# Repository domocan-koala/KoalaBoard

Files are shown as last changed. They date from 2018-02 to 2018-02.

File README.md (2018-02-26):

# KoalaBoard

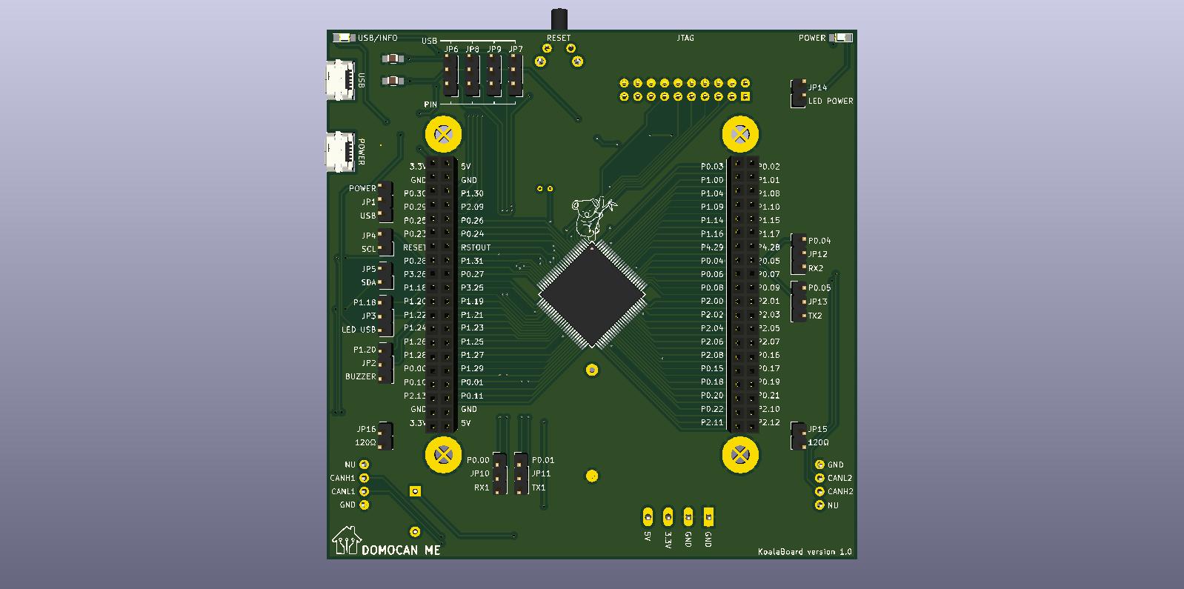
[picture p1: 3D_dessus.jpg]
Koalaboard Domocan


## Présentation

La KoalaBoard permet d'intégrer facilement la technologie ARM Cortex-M3 dans le système domotique [Domocan Master Édition](https://www.abcelectronique.com/bigonoff/forum/forumdisplay.php?fid=22). Ses deux connecteurs regroupent l’intégralité des entrées et sorties disponibles pour accueillir une [carte fille](https://github.com/domocan-koala/KoalaBoard_Carte-fille-template) complémentaire qui viendra spécialiser son utilisation dans votre installation. Les options disponibles se configurent grâce à des jumpers en fonction des besoins de l’utilisateur et de la carte fille qui va lui être associée.

## Caractéristiques techniques

* Alimentation 5V micro USB
* LPC1768 cadencé à 100MHz
* Connecteur JTAG 2x10 pins
* USB Slave
* Deux drivers CAN (*SN65HVD230*)
* Mémoire EEPROM (*24LC512*)
* Buzzer
* Support de pile 2032 et quartz pour le RTC
* Une led USB/INFO

## Configuration des jumpers

* **JP1** : Sélection de l'alimentation. (*Sans jumper, la carte doit être alimentée par la carte fille*)
* **JP2** : Active le Buzzer. (*La carte fille ne peut plus utiliser P1.20*)
* **JP3** : Active la LED USB/INFO. (*La carte fille ne peut plus utiliser P1.18*)
* **JP4** et **JP5** : Active la mémoire EEPROM. (*Ainsi que les deux résistances de pullup 4.7K*)
* **JP6**, **JP7**, **JP8** et **JP9** : Active l'USB Slave. (*La carte fille ne peut plus utiliser P0.29, P0.30, P1.30 et P2.09*)
* **JP10** et **JP11** : Active CAN1. (*La carte fille ne peut plus utiliser P0.00 et P0.01*)
* **JP12** et **JP13** : Active CAN2. (*La carte fille ne peut plus utiliser P0.04 et P0.05*)
* **JP14** : Active la LED POWER
* **JP15** : Active la résistance de terminaison CAN2
* **JP16** : Active la résistance de terminaison CAN1

## Historique
	
	* 23/02/18 V1.0 : Première version mise en ligne

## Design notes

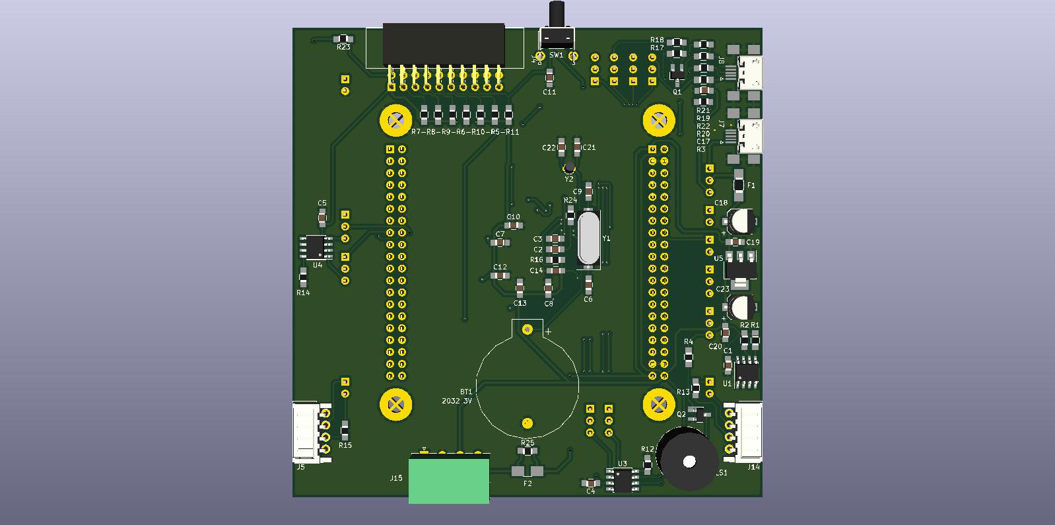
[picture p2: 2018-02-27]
3D_dessous.jpg

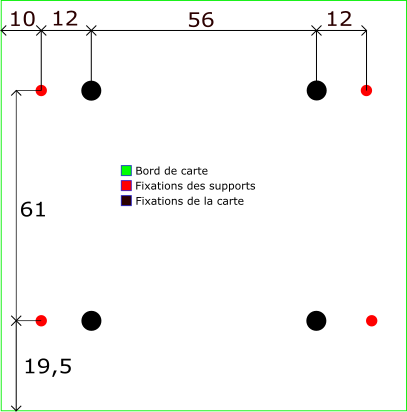
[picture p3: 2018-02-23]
Fixations.png

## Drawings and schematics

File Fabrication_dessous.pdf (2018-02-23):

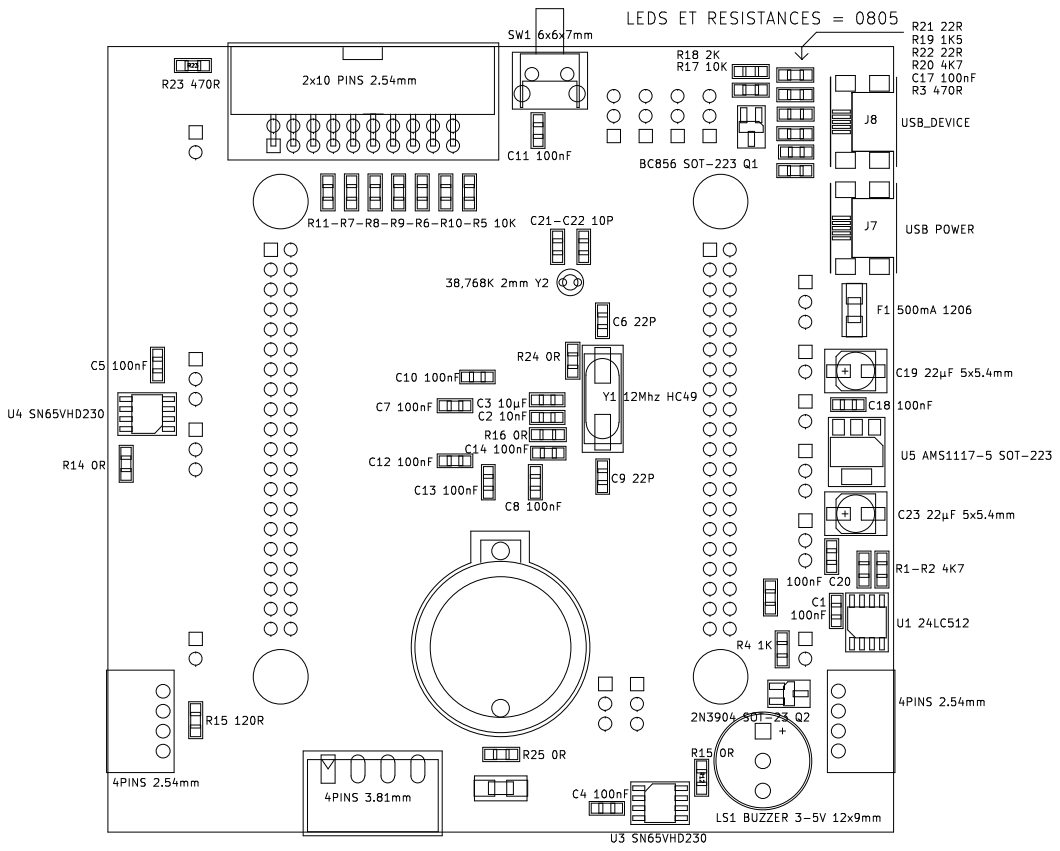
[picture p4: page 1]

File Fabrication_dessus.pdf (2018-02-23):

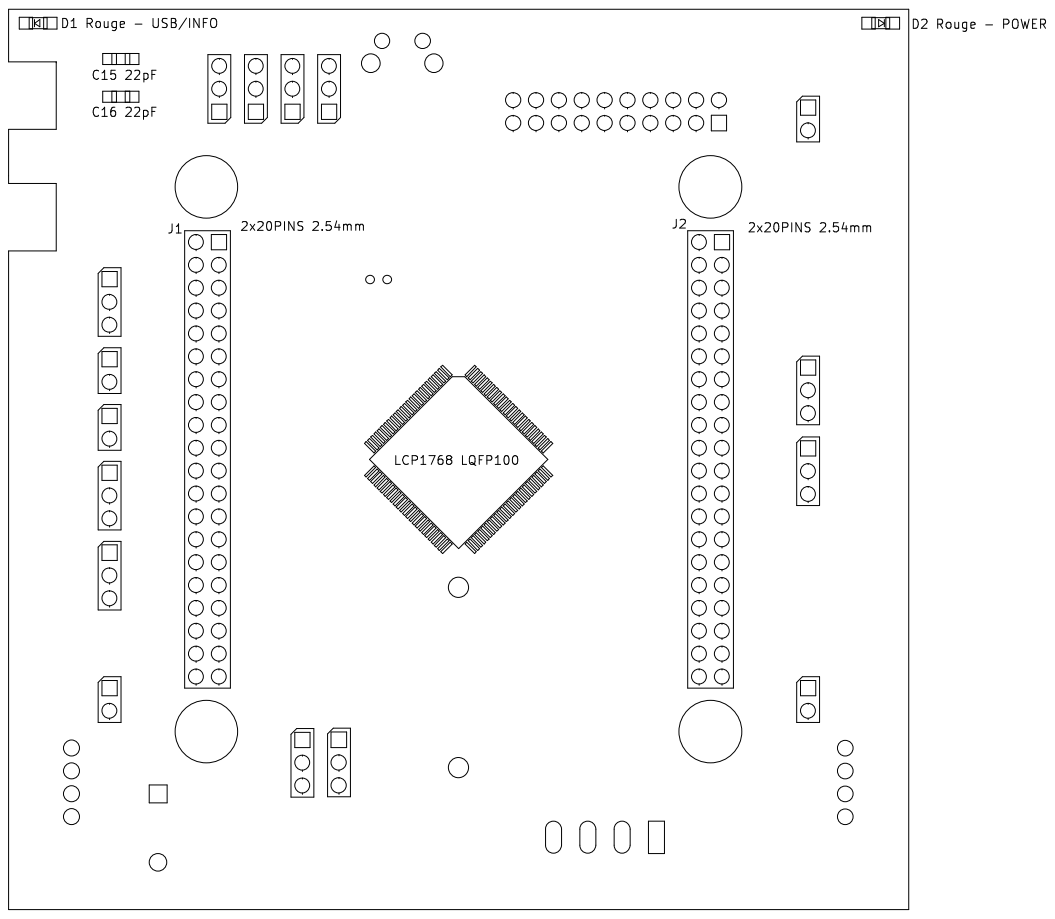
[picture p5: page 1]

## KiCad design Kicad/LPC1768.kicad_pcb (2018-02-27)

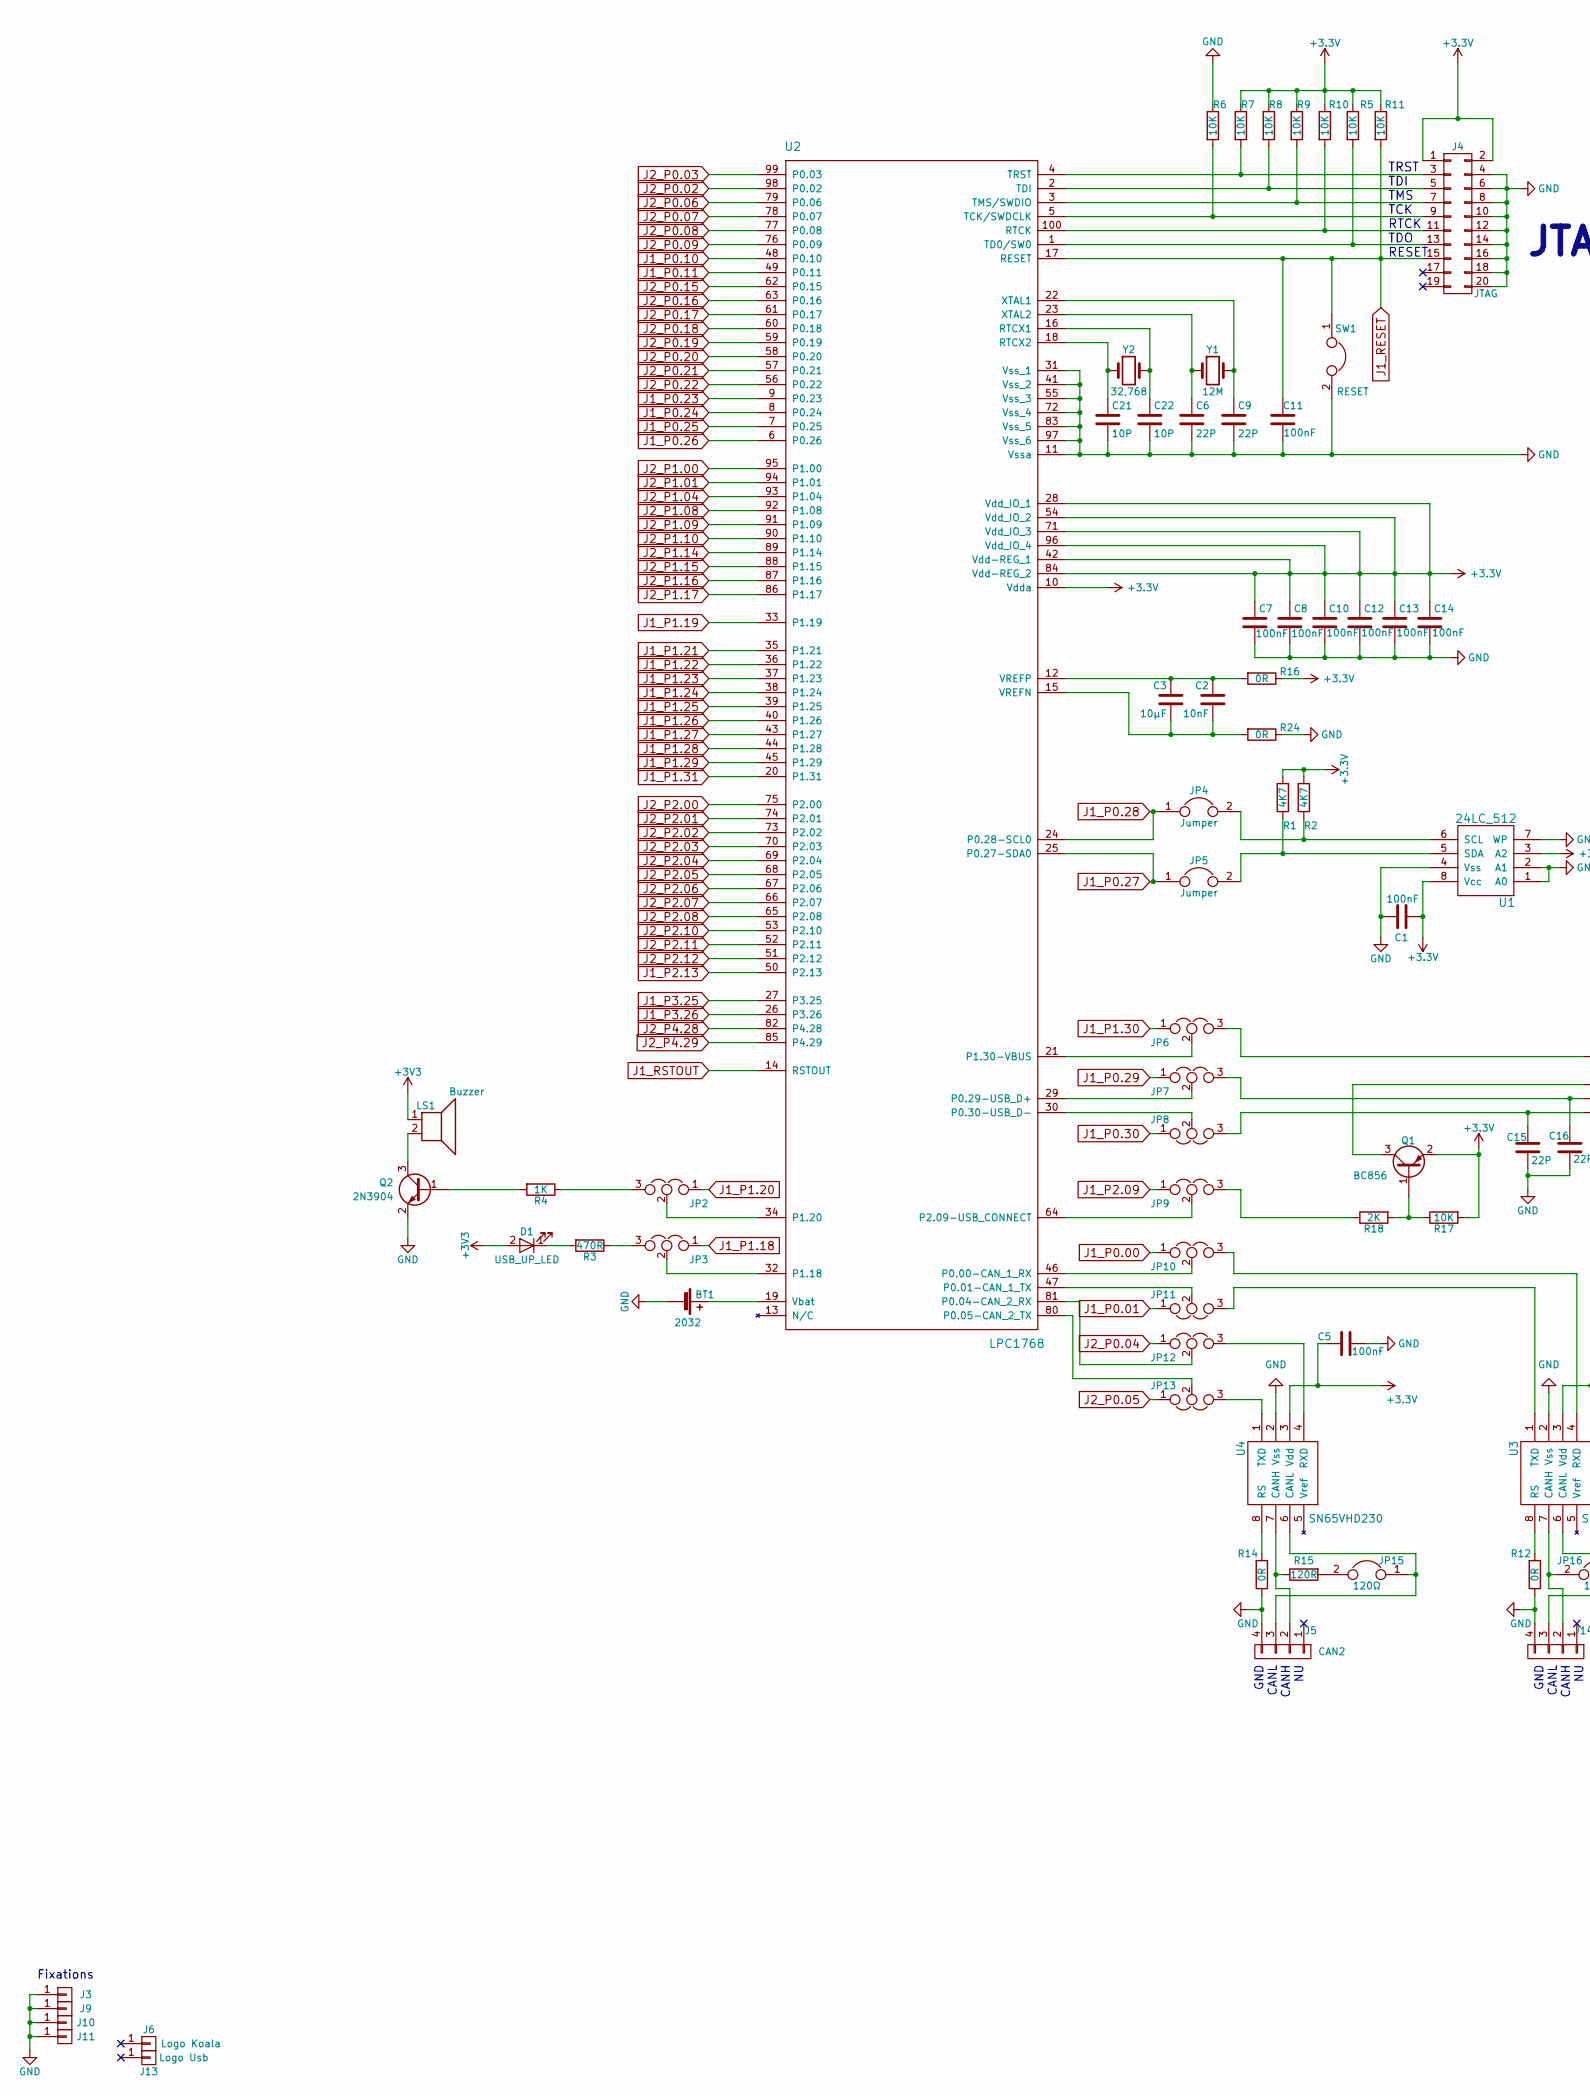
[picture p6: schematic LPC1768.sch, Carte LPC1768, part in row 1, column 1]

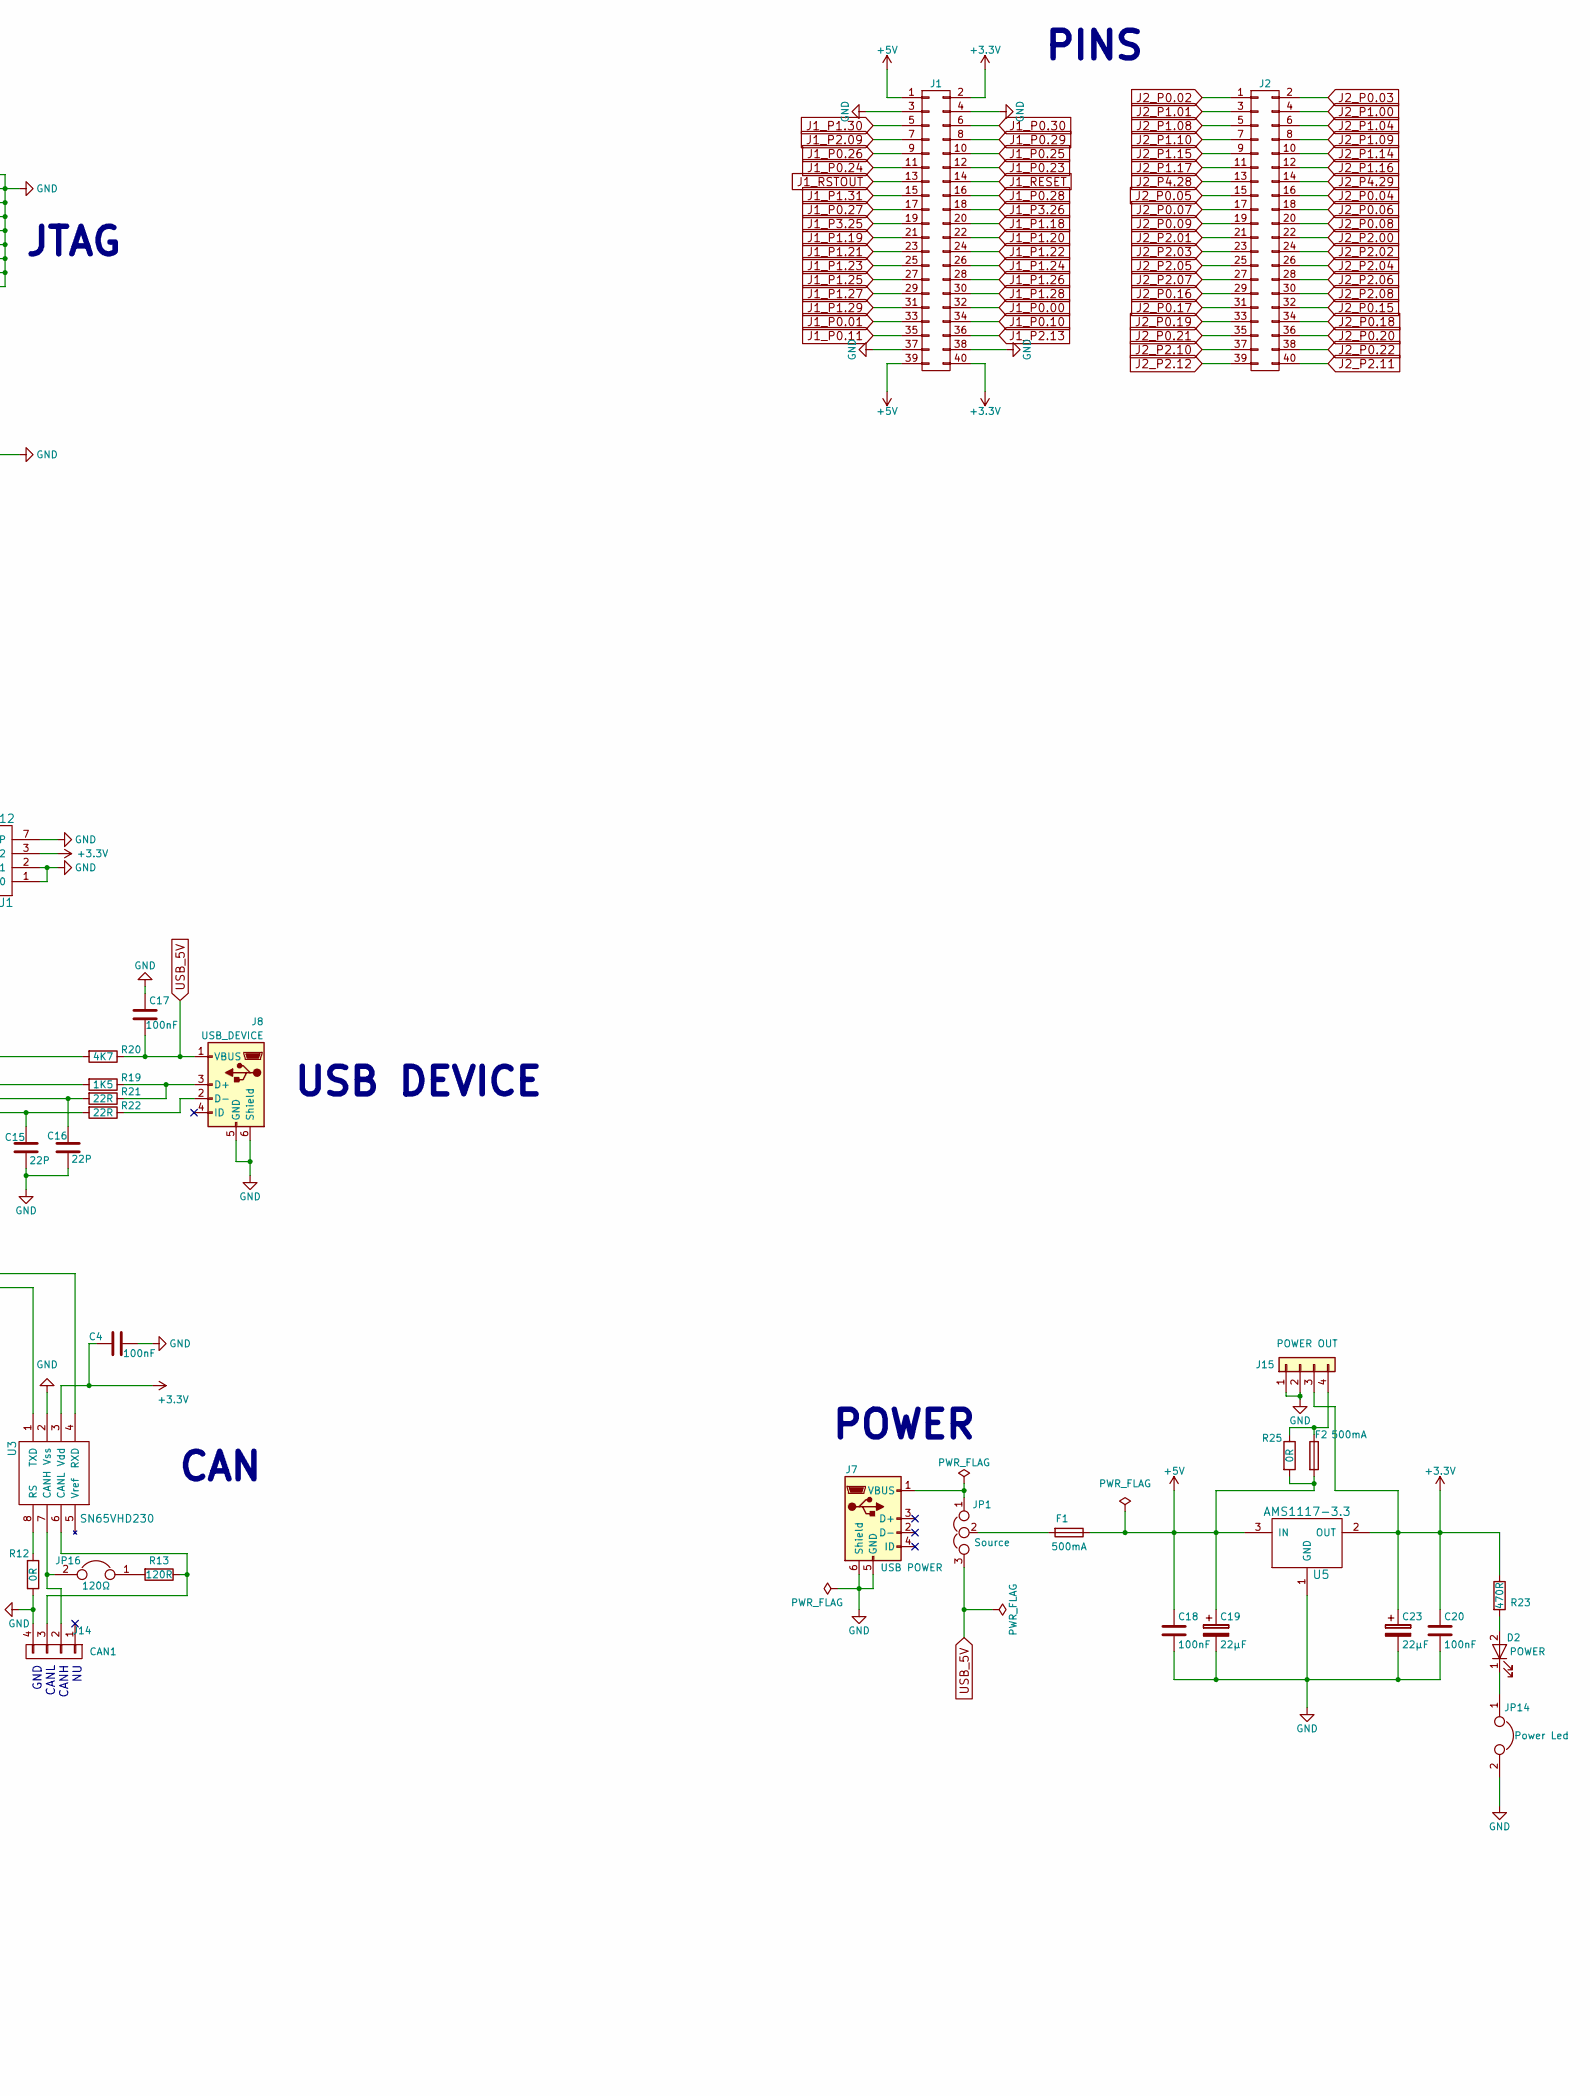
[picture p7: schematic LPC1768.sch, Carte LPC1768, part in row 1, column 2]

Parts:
BT1: 2032; 2032H
C1, C4, C5, C7, C8, C10, C11, C12, C13, C14, C17, C18, C20: 100nF; C_0805_HandSoldering
C2: 10nF; C_0805_HandSoldering
C3: 10µF; C_0805_HandSoldering
C6, C9, C15, C16: 22P; C_0805_HandSoldering
C19, C23: 22µF; CP_Elec_5x5.3
C21, C22: 10P; C_0805_HandSoldering
D1: USB_UP_LED; LED_0805_HandSoldering
D2: POWER; LED_0805_HandSoldering
F1, F2: 500mA; Fuse_SMD1206_HandSoldering
J1, J2: CONN_02X20; Socket_Strip_Straight_2x20_Pitch2.54mm
J3, J9, J10, J11: CONN_01X01; MountingHole_3.5mm_Pad
J4: JTAG; JTAG_Angle_20Pins_Pitch2.54mm
J5: CAN2; Pin_Header_Angled_1x04
J6: Logo Koala; koala
J7: USB POWER; USB_Micro_B_0.65mm
J8: USB_DEVICE; USB_Micro_B_0.65mm
J13: Logo Usb; usb
J14: CAN1; Pin_Header_Angled_1x04
J15: POWER OUT; PhoenixContact_MC-G_04x3.81mm_Angled
JP1: Source; Pin_Header_Straight_1x03_Pitch2.54mm
JP2, JP3, JP9, JP10, JP11, JP12, JP13: USB_CONNECT / P2.09; Pin_Header_Straight_1x03_Pitch2.54mm
JP4, JP5: Jumper; Pin_Header_Straight_1x02_Pitch2.54mm
JP6: VBUS / P1.30; Pin_Header_Straight_1x03_Pitch2.54mm
JP7: USB_D+ / P0.29; Pin_Header_Straight_1x03_Pitch2.54mm
JP8: USB_D- / P0.30; Pin_Header_Straight_1x03_Pitch2.54mm
JP14: Power Led; Pin_Header_Straight_1x02_Pitch2.54mm
JP15, JP16: 120Ω; Pin_Header_Straight_1x02_Pitch2.54mm
LS1: Buzzer; Buzzer_12x9.5RM7.6
Q1: BC856; SOT-23_Handsoldering
Q2: 2N3904; SOT-23_Handsoldering
R1, R2, R20: 4K7; R_0805_HandSoldering
R3, R23: 470R; R_0805_HandSoldering
R4: 1K; R_0805_HandSoldering
R5, R6, R7, R8, R9, R10, R11, R17: 10K; R_0805_HandSoldering
R12, R14, R16, R24, R25: 0R; R_0805_HandSoldering
R13, R15: 120R; R_0805_HandSoldering
R18: 2K; R_0805_HandSoldering
R19: 1K5; R_0805_HandSoldering
R21, R22: 22R; R_0805_HandSoldering
SW1: RESET; SW_Tactile_SPST_Angled_PTS645Vx83-2LFS
U1: 24LC_512; SOIC-8_3.9x4.9mm_Pitch1.27mm
U2: LPC1768; LQFP-100_14x14mm_Pitch0.5mm
U3, U4: SN65VHD230; SOIC-8_3.9x4.9mm_Pitch1.27mm
U5: AMS1117-3.3; SOT-223
Y1: 12M; Crystal_SMD_HC49-SD
Y2: 32,768; Crystal_Round_d2.0mm_Vertical

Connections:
+5V: C18.1, C19.1, F1.1, F2.2, J1.1, J1.39, R25.2, U5.3 (IN)
GND: BT1.2 (-), C1.1, C4.2, C5.2, C6.2, C7.2, C8.2, C9.2, C10.2, C11.1, C12.2, C13.2, C14.2, C15.1, C16.2, C17.1, C18.2, C19.2, C20.2, C21.2, C22.2, C23.2, J1.3, J1.4, J1.37, J1.38, J3.1, J4.4, J4.6, J4.8, J4.10, J4.12, J4.14, J4.16, J4.18, J4.20, J5.4, J7.5 (GND), J7.6 (Shield), J8.5 (GND), J8.6 (Shield), J9.1, J10.1, J11.1, J14.4, J15.1, J15.2, JP14.2, Q2.2 (E), R6.1, R12.1, R14.1, R24.1, SW1.2, U1.1 (A0), U1.2 (A1), U1.4 (Vss), U1.7 (WP), U2.11 (Vssa), U2.31 (Vss_1), U2.41 (Vss_2), U2.55 (Vss_3), U2.72 (Vss_4), U2.83 (Vss_5), U2.97 (Vss_6), U3.2 (Vss), U4.2 (Vss), U5.1 (GND)
J1_P0.00: J1.32, JP10.1
J1_P0.01: J1.33, JP11.1
J1_P0.10: J1.34, U2.48 (P0.10)
J1_P0.11: J1.35, U2.49 (P0.11)
J1_P0.23: J1.12, U2.9 (P0.23)
J1_P0.24: J1.11, U2.8 (P0.24)
J1_P0.25: J1.10, U2.7 (P0.25)
J1_P0.26: J1.9, U2.6 (P0.26)
J1_P0.27: J1.17, JP5.1, U2.25 (P0.27-SDA0)
J1_P0.28: J1.16, JP4.1, U2.24 (P0.28-SCL0)
J1_P0.29: J1.8, JP7.1
J1_P0.30: J1.6, JP8.1
J1_P1.18: J1.20, JP3.1
J1_P1.19: J1.21, U2.33 (P1.19)
J1_P1.20: J1.22, JP2.1
J1_P1.21: J1.23, U2.35 (P1.21)
J1_P1.22: J1.24, U2.36 (P1.22)
J1_P1.23: J1.25, U2.37 (P1.23)
J1_P1.24: J1.26, U2.38 (P1.24)
J1_P1.25: J1.27, U2.39 (P1.25)
J1_P1.26: J1.28, U2.40 (P1.26)
J1_P1.27: J1.29, U2.43 (P1.27)
J1_P1.28: J1.30, U2.44 (P1.28)
J1_P1.29: J1.31, U2.45 (P1.29)
J1_P1.30: J1.5, JP6.1
J1_P1.31: J1.15, U2.20 (P1.31)
J1_P2.09: J1.7, JP9.1
J1_P2.13: J1.36, U2.50 (P2.13)
J1_P3.25: J1.19, U2.27 (P3.25)
J1_P3.26: J1.18, U2.26 (P3.26)
J1_RESET: C11.2, J1.14, J4.15, R11.2, SW1.1, U2.17 (RESET)
J1_RSTOUT: J1.13, U2.14 (RSTOUT)
J2_P0.02: J2.1, U2.98 (P0.02)
J2_P0.03: J2.2, U2.99 (P0.03)
J2_P0.04: J2.16, JP12.1
J2_P0.05: J2.15, JP13.1
J2_P0.06: J2.18, U2.79 (P0.06)
J2_P0.07: J2.17, U2.78 (P0.07)
J2_P0.08: J2.20, U2.77 (P0.08)
J2_P0.09: J2.19, U2.76 (P0.09)
J2_P0.15: J2.32, U2.62 (P0.15)
J2_P0.16: J2.29, U2.63 (P0.16)
J2_P0.17: J2.31, U2.61 (P0.17)
J2_P0.18: J2.34, U2.60 (P0.18)
J2_P0.19: J2.33, U2.59 (P0.19)
J2_P0.20: J2.36, U2.58 (P0.20)
J2_P0.21: J2.35, U2.57 (P0.21)
J2_P0.22: J2.38, U2.56 (P0.22)
J2_P1.00: J2.4, U2.95 (P1.00)
J2_P1.01: J2.3, U2.94 (P1.01)
J2_P1.04: J2.6, U2.93 (P1.04)
J2_P1.08: J2.5, U2.92 (P1.08)
J2_P1.09: J2.8, U2.91 (P1.09)
J2_P1.10: J2.7, U2.90 (P1.10)
J2_P1.14: J2.10, U2.89 (P1.14)
J2_P1.15: J2.9, U2.88 (P1.15)
J2_P1.16: J2.12, U2.87 (P1.16)
J2_P1.17: J2.11, U2.86 (P1.17)
J2_P2.00: J2.22, U2.75 (P2.00)
J2_P2.01: J2.21, U2.74 (P2.01)
J2_P2.02: J2.24, U2.73 (P2.02)
J2_P2.03: J2.23, U2.70 (P2.03)
J2_P2.04: J2.26, U2.69 (P2.04)
J2_P2.05: J2.25, U2.68 (P2.05)
J2_P2.06: J2.28, U2.67 (P2.06)
J2_P2.07: J2.27, U2.66 (P2.07)
J2_P2.08: J2.30, U2.65 (P2.08)
J2_P2.10: J2.37, U2.53 (P2.10)
J2_P2.11: J2.40, U2.52 (P2.11)
J2_P2.12: J2.39, U2.51 (P2.12)
J2_P4.28: J2.13, U2.82 (P4.28)
J2_P4.29: J2.14, U2.85 (P4.29)
unnamed: BT1.1 (+), U2.19 (Vbat)
unnamed: C2.1, C3.1, R16.2, U2.12 (VREFP)
unnamed: C2.2, C3.2, R24.2, U2.15 (VREFN)
unnamed: C6.1, U2.23 (XTAL2), Y1.1
unnamed: C9.1, U2.22 (XTAL1), Y1.2
unnamed: C15.2, JP8.3, R22.2
unnamed: C16.1, JP7.3, R21.2
unnamed: C21.1, U2.18 (RTCX2), Y2.1
unnamed: C22.1, U2.16 (RTCX1), Y2.2
unnamed: D1.1 (K), R3.2
unnamed: D2.1 (K), JP14.1
unnamed: D2.2 (A), R23.2
unnamed: F1.2, JP1.2
unnamed: F2.1, J15.4, R25.1
unnamed: J4.3, R7.2, U2.4 (TRST)
unnamed: J4.5, R8.2, U2.2 (TDI)
unnamed: J4.7, R9.2, U2.3 (TMS/SWDIO)
unnamed: J4.9, R6.2, U2.5 (TCK/SWDCLK)
unnamed: J4.11, R10.2, U2.100 (RTCK)
unnamed: J4.13, R5.2, U2.1 (TD0/SW0)
unnamed: J5.2, R15.1, U4.7 (CANH)
unnamed: J5.3, JP15.1, U4.6 (CANL)
unnamed: J7.1 (VBUS), JP1.1
unnamed: J8.2 (D-), R22.1
unnamed: J8.3 (D+), R19.1, R21.1
unnamed: J14.2, JP16.2, U3.7 (CANH)
unnamed: J14.3, R13.1, U3.6 (CANL)
unnamed: JP2.2, U2.34 (P1.20)
unnamed: JP2.3, R4.1
unnamed: JP3.2, U2.32 (P1.18)
unnamed: JP3.3, R3.1
unnamed: JP4.2, R2.1, U1.6 (SCL)
unnamed: JP5.2, R1.1, U1.5 (SDA)
unnamed: JP6.2, U2.21 (P1.30-VBUS)
unnamed: JP6.3, R20.2
unnamed: JP7.2, U2.29 (P0.29-USB_D+)
unnamed: JP8.2, U2.30 (P0.30-USB_D-)
unnamed: JP9.2, U2.64 (P2.09-USB_CONNECT)
unnamed: JP9.3, R18.1
unnamed: JP10.2, U2.46 (P0.00-CAN_1_RX)
unnamed: JP10.3, U3.4 (RXD)
unnamed: JP11.2, U2.47 (P0.01-CAN_1_TX)
unnamed: JP11.3, U3.1 (TXD)
unnamed: JP12.2, U2.81 (P0.04-CAN_2_RX)
unnamed: JP12.3, U4.4 (RXD)
unnamed: JP13.2, U2.80 (P0.05-CAN_2_TX)
unnamed: JP13.3, U4.1 (TXD)
unnamed: JP15.2, R15.2
unnamed: JP16.1, R13.2
unnamed: LS1.2, Q2.3 (C)
unnamed: Q1.1 (B), R17.1, R18.2
unnamed: Q1.3 (C), R19.2
unnamed: Q2.1 (B), R4.2
unnamed: R12.2, U3.8 (RS)
unnamed: R14.2, U4.8 (RS)
USB_5V: C17.2, J8.1 (VBUS), JP1.3, R20.1

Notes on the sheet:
USB DEVICE
POWER
TRST TDI TMS TCK RTCK TDO RESET
GND CANL CANH NU
PINS
JTAG
CAN
Fixations

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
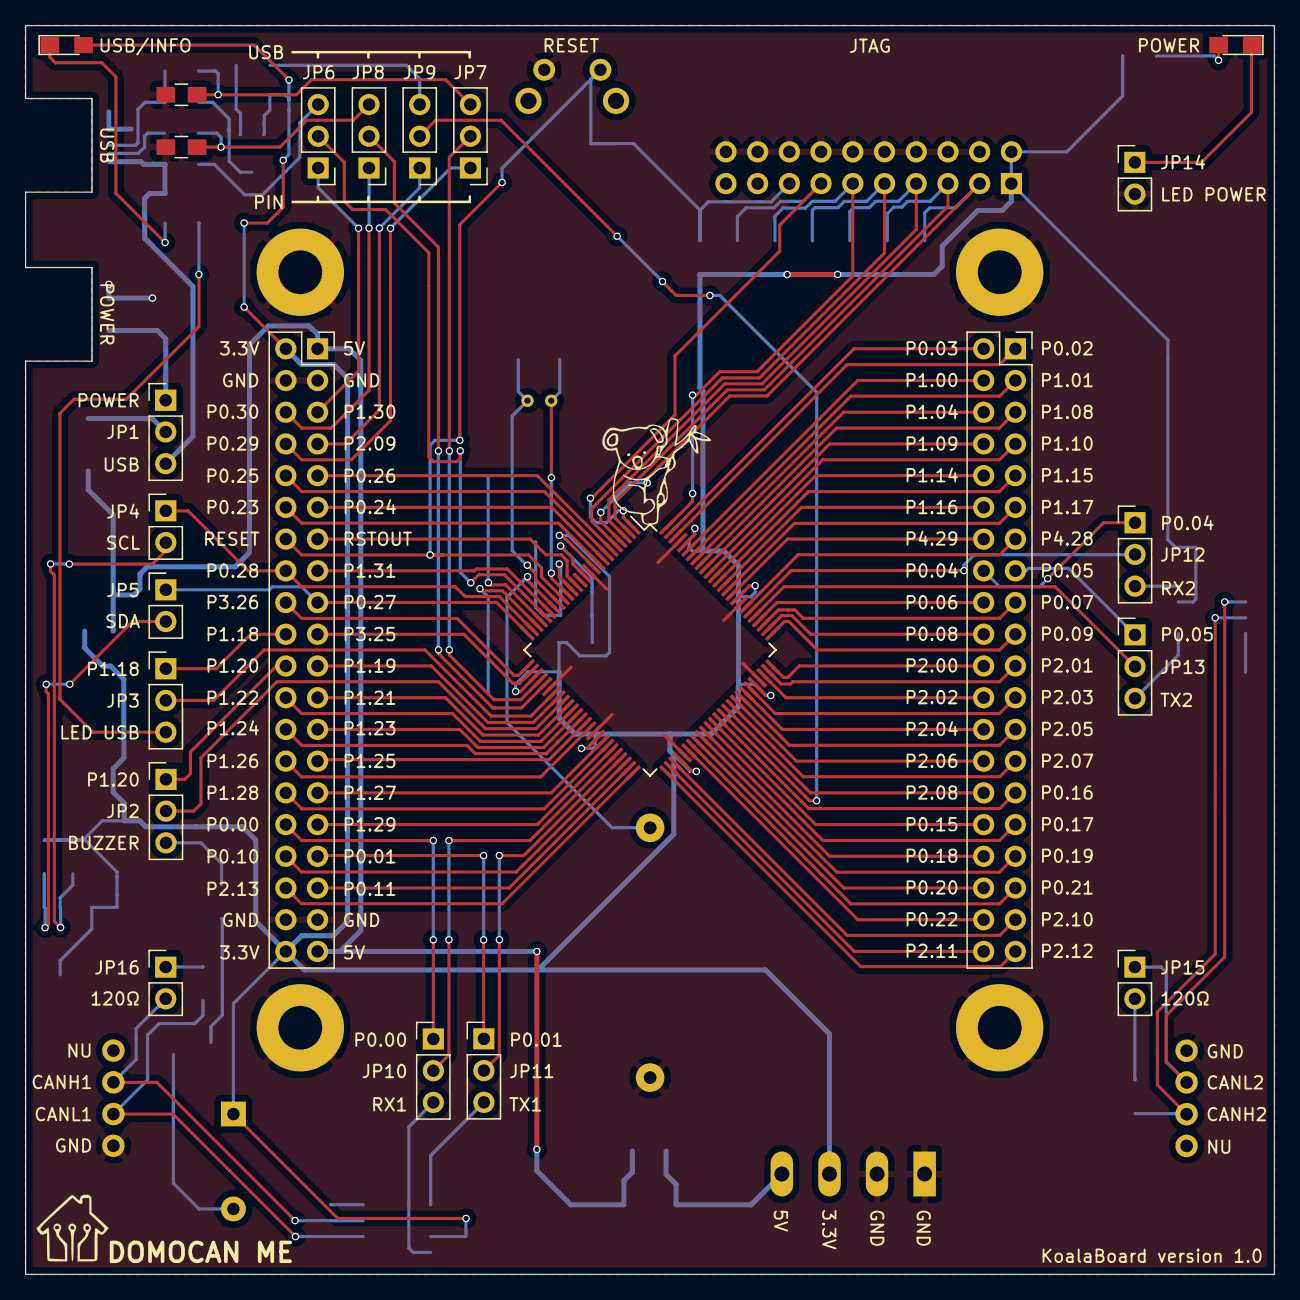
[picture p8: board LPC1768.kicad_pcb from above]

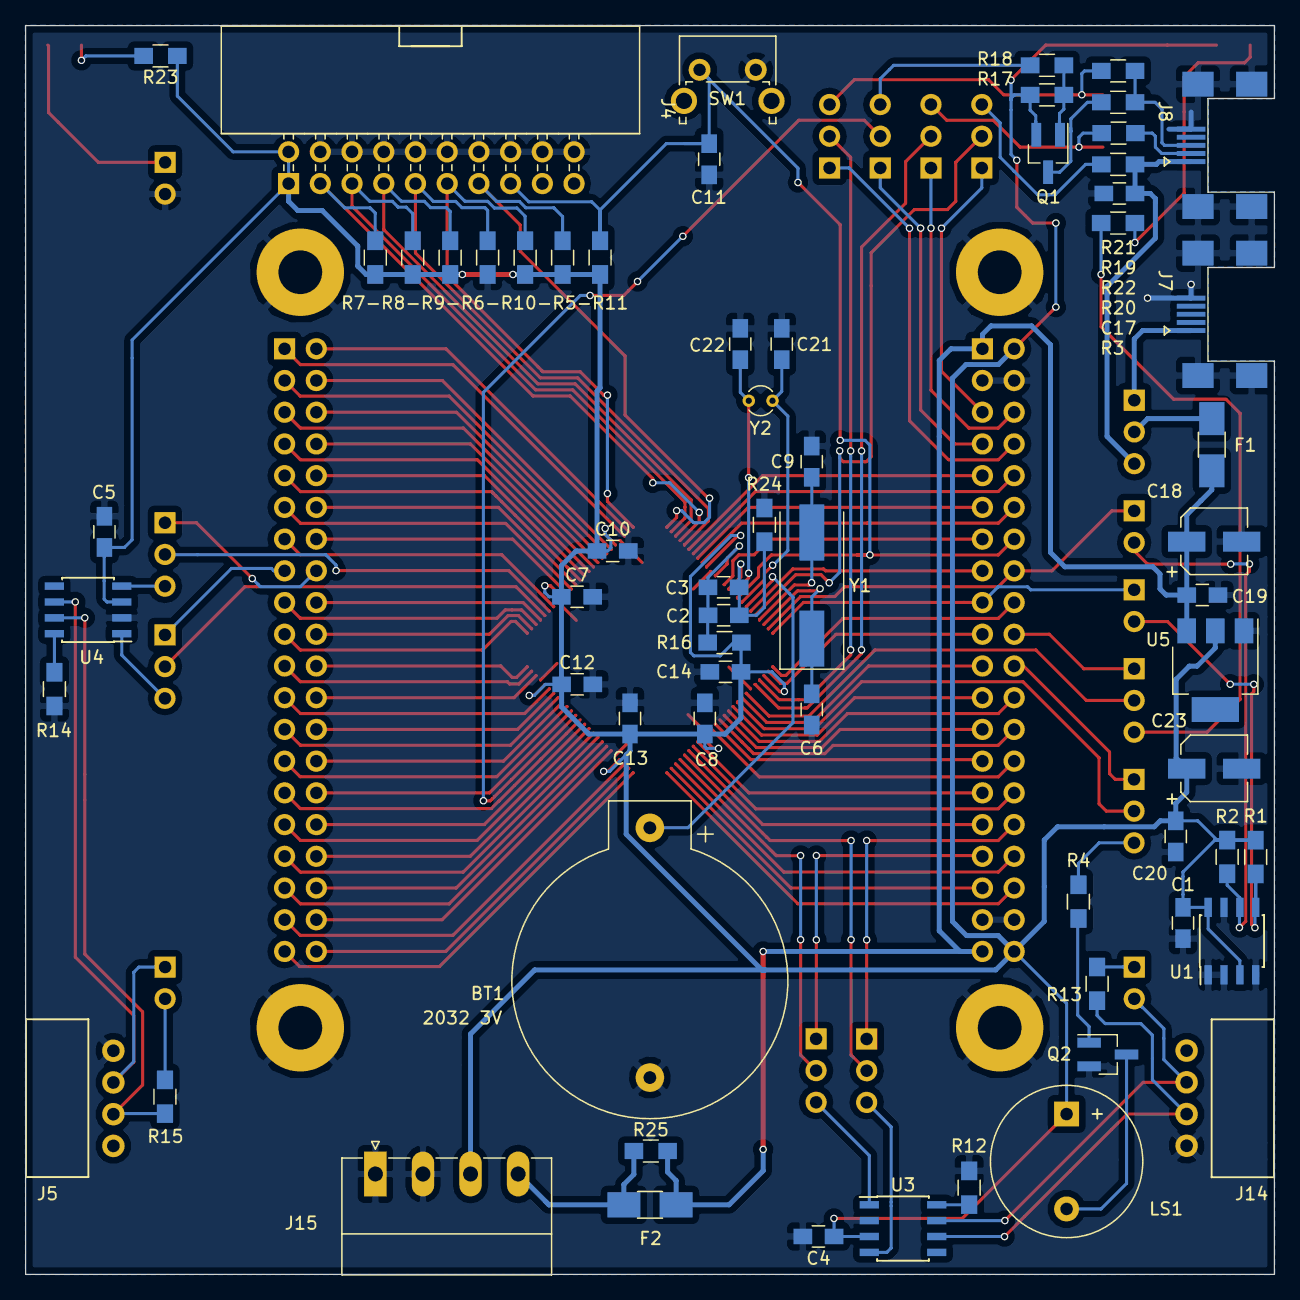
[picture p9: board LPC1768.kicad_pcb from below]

Board: 2 copper layers, 100.0 x 100.0 mm, 94 parts (65 on the bottom side), 131 nets.

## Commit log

2018-02-23 Première mise en ligne
    Carte mère KoalaBoard pour Domocan
    [LPC1768.kicad_pcb, LPC1768.sch]
2018-02-26 Documentation
    Mise à jour de la documentation
2018-02-27 Correction vue 3D
    [LPC1768.kicad_pcb]
